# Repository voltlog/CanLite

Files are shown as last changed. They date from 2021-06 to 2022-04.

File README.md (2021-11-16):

# Voltlog CanLite
This repository contains the source files for the CanLite, an ESP32 based CAN development/hacking board which features a built-in automotive grade dc-dc converter as well as an optional two channel high-side automotive grade switch capable of switching up to 1.8A per channel with plenty of protection features.

More info about this project in [Voltlog #370](https://youtu.be/DLKQcw506ck) & [Voltlog #390](https://youtu.be/_m2UW_pron4).
If you would like to order one of these boards ready assembled, check out my [Tindie store](https://voltlog.com/y/canlite).

### Changelog
- revD: Switched to a different inductor, [different high-side switch](https://www.infineon.com/dgdl/Infineon-BTS452T-DS-v01_01-EN.pdf?fileId=5546d4625a888733015aa9afaf0f35d1), optimised layout.
- revC: Switched to a different inductor pn, added some IO access via test points.
- revB: Fixed some bugs from revA.
- revA: Initial release.

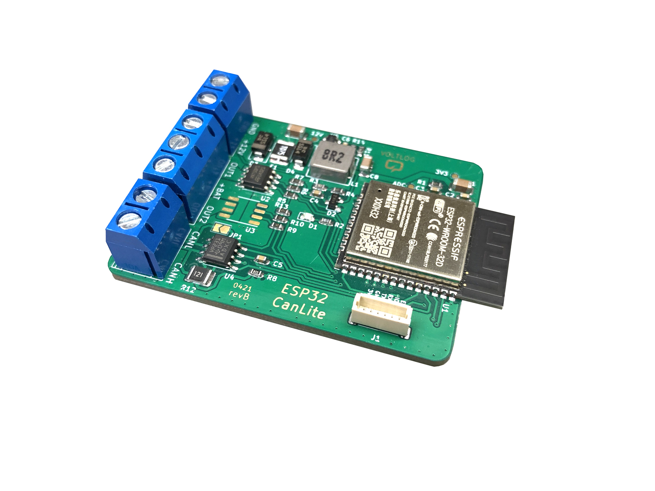
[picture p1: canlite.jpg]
Image of the assembled PCB


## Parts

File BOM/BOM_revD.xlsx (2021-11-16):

Qty | Reference(s) | Value | Footprint | Datasheet | LCSC | PN | Voltage
5 | C1, C4, C6, C7, C8 | 0.1uF | Capacitor_SMD:C_0603_1608Metric | ~
2 | C2, C3 | 10uF | Capacitor_SMD:C_1206_3216Metric | https://datasheet.lcsc.com/szlcsc/1912111437_Murata-Electronics-GRM21BR61E106MA73L_C391262.pdf | C391262 | GRM21BR61E106MA73L | 35V
1 | C5 | 22uF | Capacitor_SMD:C_1206_3216Metric | https://datasheet.lcsc.com/szlcsc/1912111437_Murata-Electronics-GRM31CR70J226KE19L_C408152.pdf | C408152 | GRM31CR70J226KE19L
2 | D1, D2 | SS14 | Diode_SMD:D_SMA | ~
1 | D3 | LED | LED_SMD:LED_0603_1608Metric | ~
1 | D4 | BAS40-04 | Package_TO_SOT_SMD:SOT-23 | http://www.vishay.com/docs/85701/bas40v.pdf
1 | F1 | 0.5A | Fuse:Fuse_1812_4532Metric | https://datasheet.lcsc.com/szlcsc/1809292114_TLC-Electronic-TLC-MSMD075_C262024.pdf | C262024 | TLC-MSMD075
1 | J1 | 12V | TerminalBlock_RND:TerminalBlock_RND_205-00232_1x02_P5.08mm_Horizontal | ~
1 | J2 | CAN | TerminalBlock_RND:TerminalBlock_RND_205-00232_1x02_P5.08mm_Horizontal | ~
1 | J3 | VOLTLINK | Connector_JST:JST_SH_BM06B-SRSS-TB_1x06-1MP_P1.00mm_Vertical | ~
1 | J4 | Conn_01x03 | TerminalBlock_RND:TerminalBlock_RND_205-00233_1x03_P5.08mm_Horizontal | ~
1 | JP1 | NO | Jumper:SolderJumper-2_P1.3mm_Open_TrianglePad1.0x1.5mm | ~
1 | L1 | 8.2uH | voltlog:Inductor_7.5x6.6 |  | C436550 | PSPMAA0603-8R2M-ANF
4 | R1, R7, R8, R10 | 10K | Resistor_SMD:R_0603_1608Metric | ~
1 | R2 | 28K | Resistor_SMD:R_0603_1608Metric | ~
1 | R3 | 8.45K | Resistor_SMD:R_0603_1608Metric | ~
1 | R4 | 1K | Resistor_SMD:R_0603_1608Metric | ~
1 | R5 | 120 | Resistor_SMD:R_1210_3225Metric | ~
1 | R6 | 100K | Resistor_SMD:R_0603_1608Metric | ~
1 | R9 | 36K | Resistor_SMD:R_0603_1608Metric | ~
1 | U1 | LMR14006 | Package_TO_SOT_SMD:SOT-23-6 | https://www.ti.com/lit/ds/symlink/lmr14006.pdf?ts=1611109108480
1 | U2 | ESP32-WROOM-32 | RF_Module:ESP32-WROOM-32 | https://www.espressif.com/sites/default/files/documentation/esp32-wroom-32d_esp32-wroom-32u_datasheet_en.pdf
1 | U3 | SN65HVD231 | Package_SO:SOIC-8_3.9x4.9mm_P1.27mm | http://www.ti.com/lit/ds/symlink/sn65hvd230.pdf
2 | U4, U5 | BTS452T | Package_TO_SOT_SMD:TO-252-4 | https://www.infineon.com/dgdl/Infineon-BTS452T-DS-v01_01-EN.pdf?fileId=5546d4625a888733015aa9afaf0f35d1

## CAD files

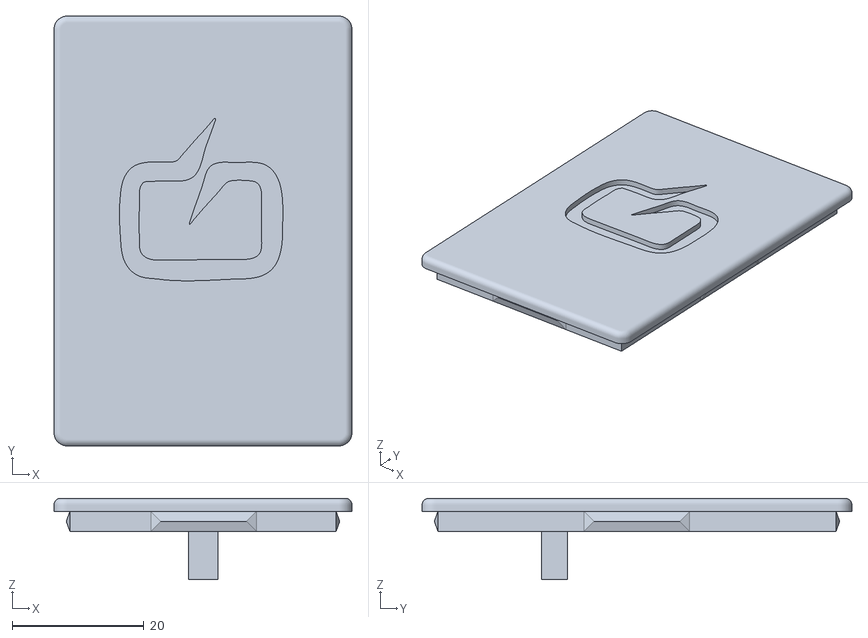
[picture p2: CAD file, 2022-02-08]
3D print enclosure/CANLite_Case/CANLite_Cover_with_Logo.stl
45.2 x 65.2 x 12.4

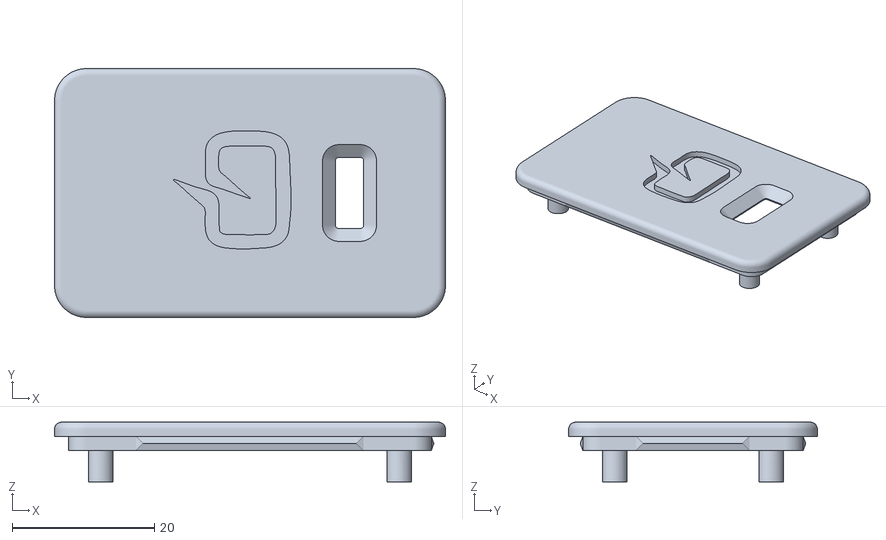
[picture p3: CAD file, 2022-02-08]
3D print enclosure/VoltLink_Case/Cover_with_Logo.stl
55.0 x 35.0 x 8.40

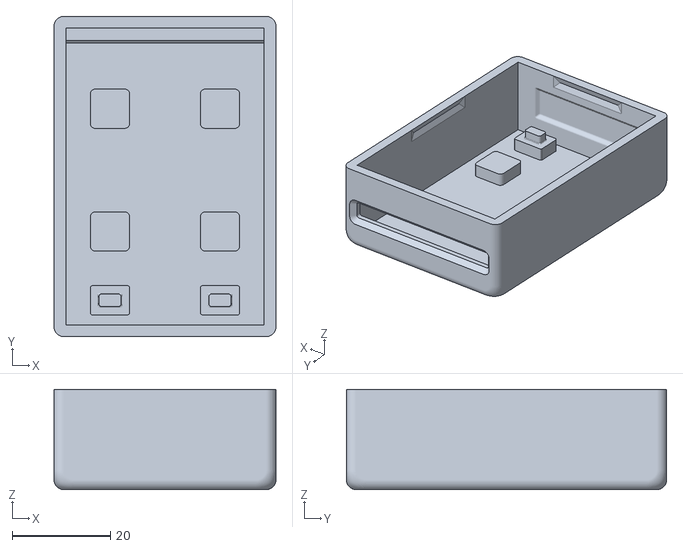
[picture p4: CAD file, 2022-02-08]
3D print enclosure/CANLite_Case/CANLite_Case.stl
45.2 x 65.2 x 20.4

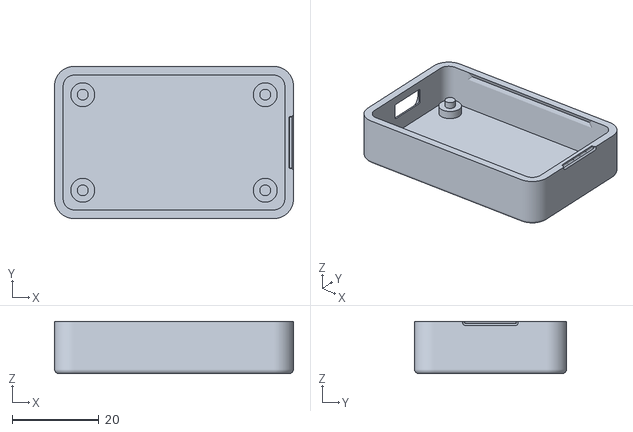
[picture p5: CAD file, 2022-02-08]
3D print enclosure/VoltLink_Case/Case.stl
55.0 x 35.0 x 12.0

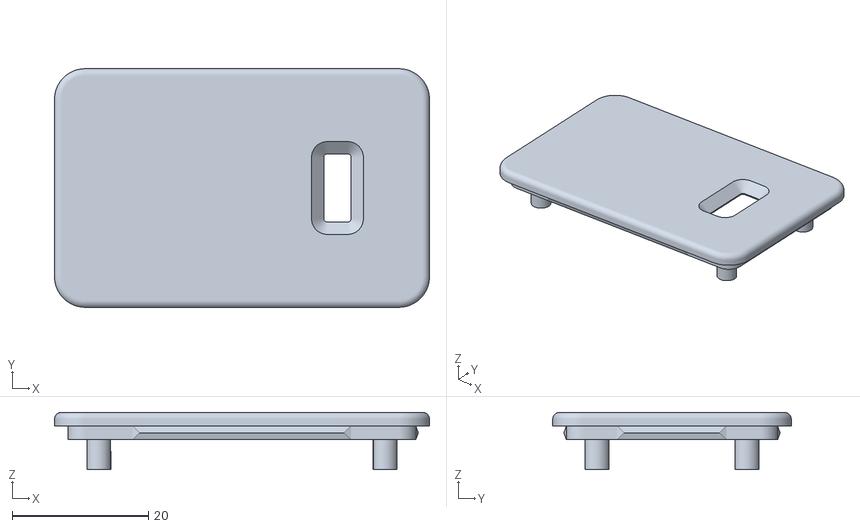
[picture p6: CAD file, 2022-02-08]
3D print enclosure/VoltLink_Case/Cover_without_Logo.stl
55.0 x 35.0 x 8.40

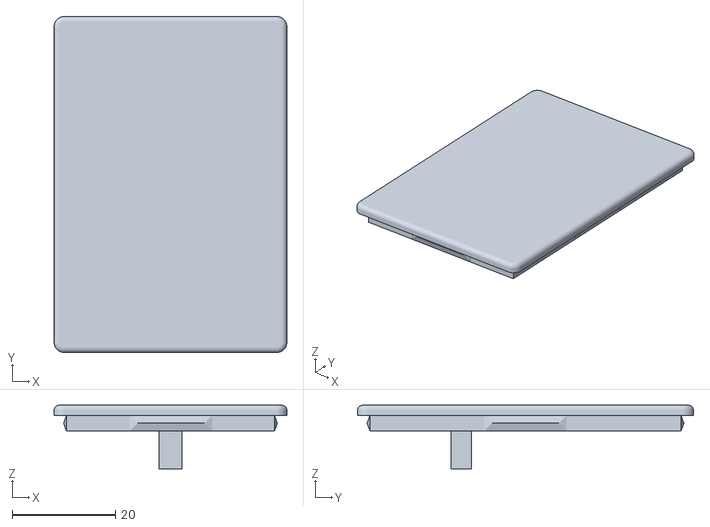
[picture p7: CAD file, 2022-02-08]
3D print enclosure/CANLite_Case/CANLite_Cover_without_Logo.stl
45.2 x 65.2 x 12.4

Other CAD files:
3D print enclosure/CANLite_Case/CANLite_Cover_without_Logo_Sharp.stl

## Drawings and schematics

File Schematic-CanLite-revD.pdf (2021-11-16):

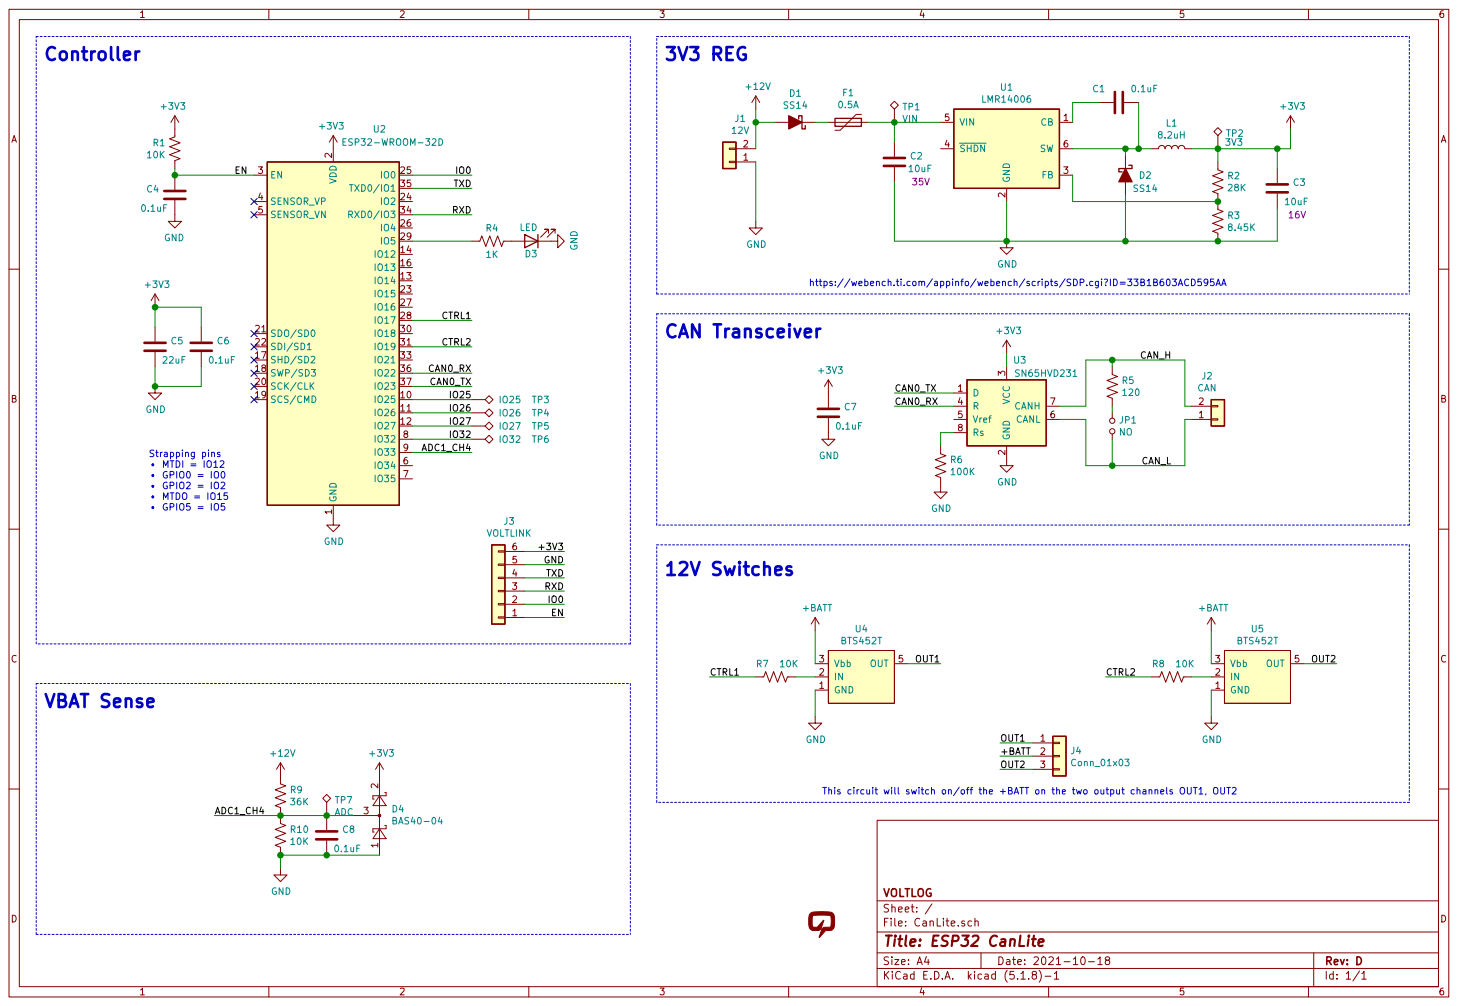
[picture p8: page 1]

2 FB 3 SHDN 4 VIN 5 SW 6 U1

2 SCK/CLK 20 SDO/SD0 21 SDI/SD1 22

https://webench.ti.com/appinfo/webench/scripts/SDP.cgi?ID=33B1B603ACD595AA

File: CanLite.sch Sheet: / VOLTLOG

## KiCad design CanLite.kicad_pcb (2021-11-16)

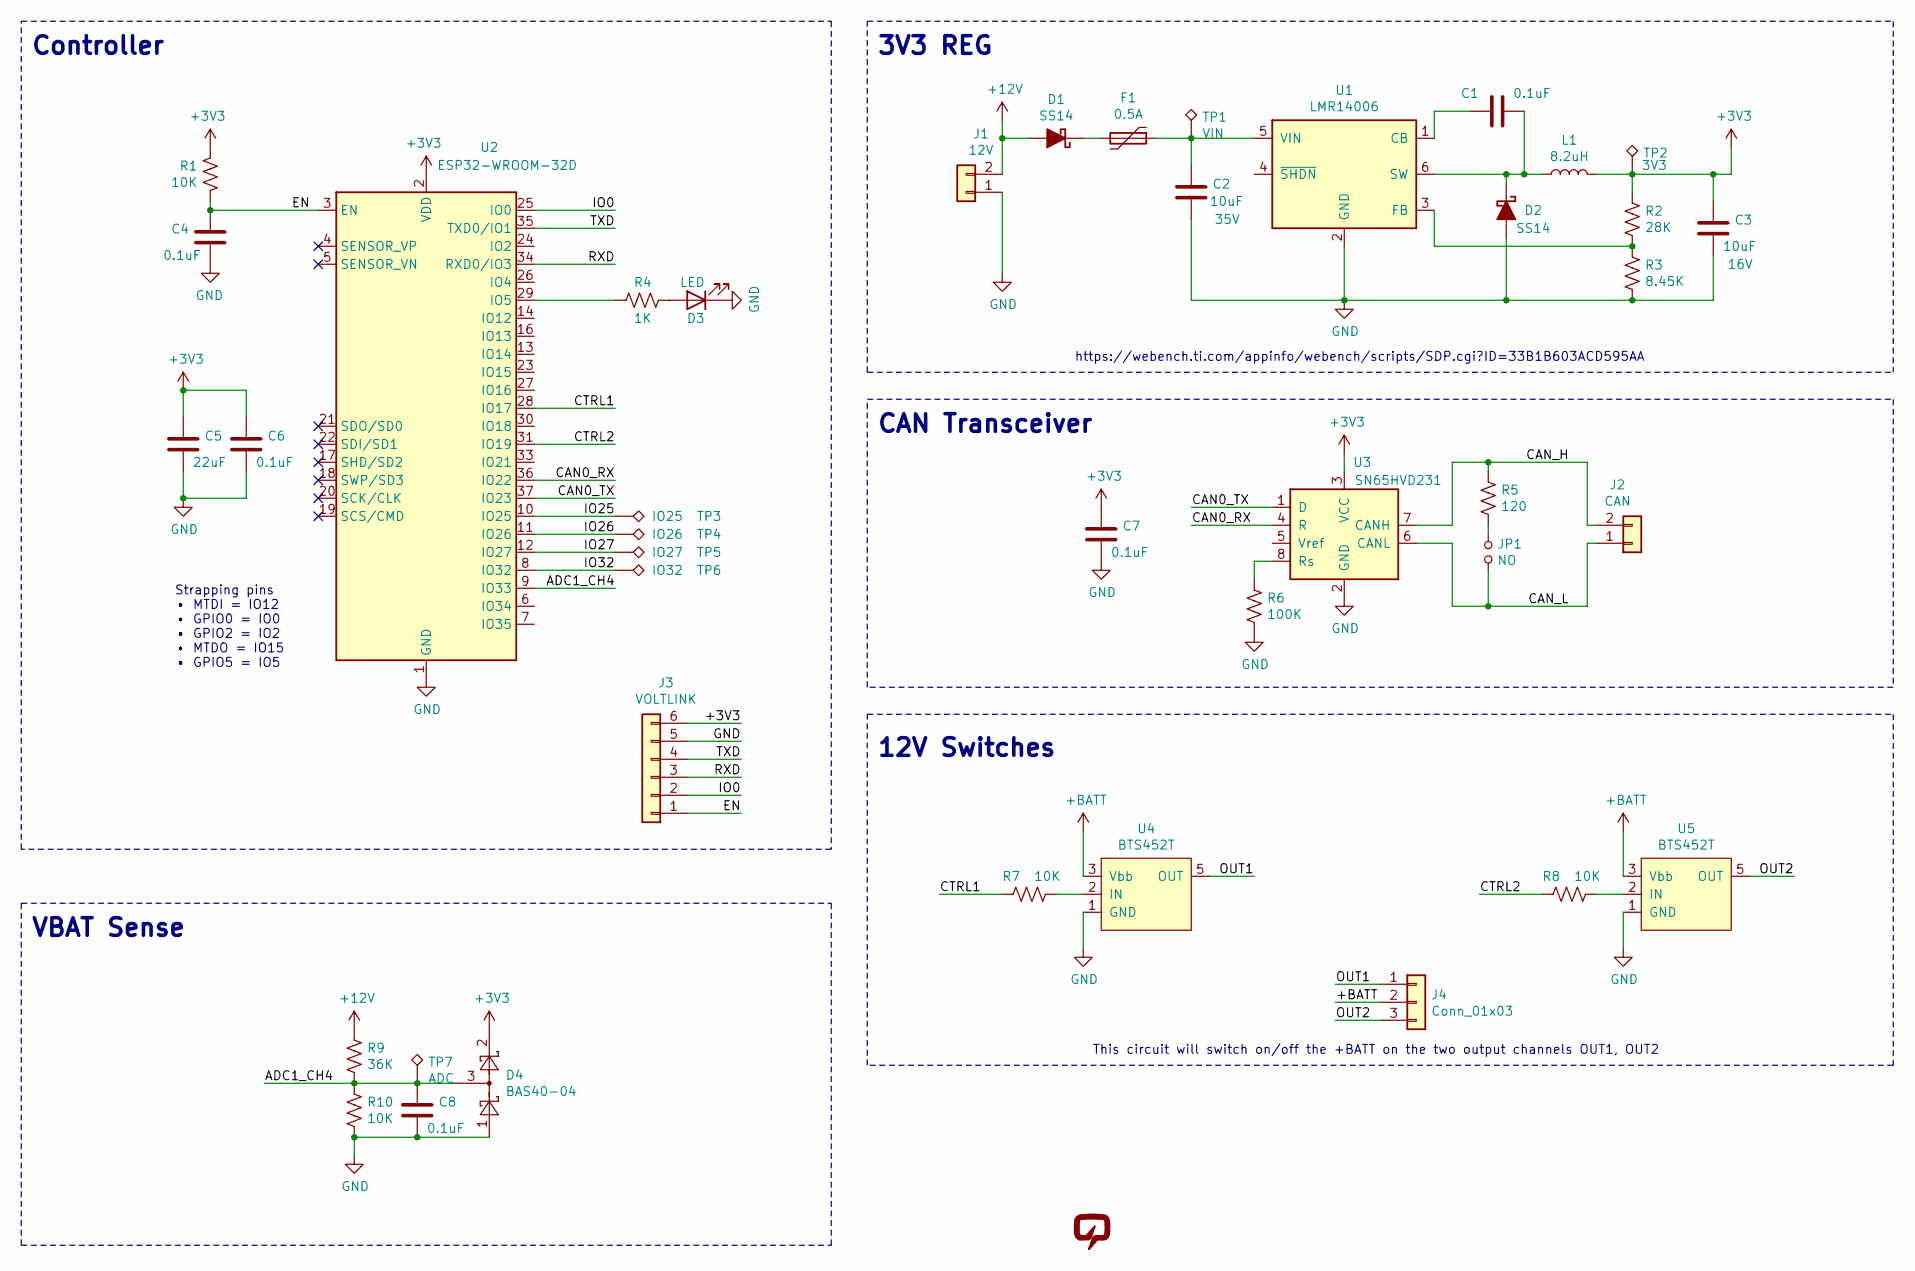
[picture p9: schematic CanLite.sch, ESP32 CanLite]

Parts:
C1, C4, C6, C7, C8: 0.1uF; C_0603_1608Metric
C2: 10uF; C_1206_3216Metric; Voltage 35V; LCSC C391262
C3: 10uF; C_1206_3216Metric; Voltage 16V; LCSC C408152
C5: 22uF; C_1206_3216Metric; LCSC C408152
D1, D2: SS14; D_SMA
D3: LED; LED_0603_1608Metric
D4: BAS40-04; SOT-23
F1: 0.5A; Fuse_1812_4532Metric; LCSC C262024
J1: 12V; TerminalBlock_RND_205-00232_1x02_P5.08mm_Horizontal
J2: CAN; TerminalBlock_RND_205-00232_1x02_P5.08mm_Horizontal
J3: VOLTLINK; JST_SH_BM06B-SRSS-TB_1x06-1MP_P1.00mm_Vertical
J4: Conn_01x03; TerminalBlock_RND_205-00233_1x03_P5.08mm_Horizontal
JP1: NO; SolderJumper-2_P1.3mm_Open_TrianglePad1.0x1.5mm
L1: 8.2uH; Inductor_7.5x6.6; LCSC C436550
R1, R7, R8, R10: 10K; R_0603_1608Metric
R2: 28K; R_0603_1608Metric
R3: 8.45K; R_0603_1608Metric
R4: 1K; R_0603_1608Metric
R5: 120; R_1210_3225Metric
R6: 100K; R_0603_1608Metric
R9: 36K; R_0603_1608Metric
TP1: VIN; TestPoint_Pad_D1.0mm
TP2: 3V3; TestPoint_Pad_D1.0mm
TP3: IO25; TestPoint_Pad_D1.0mm
TP4: IO26; TestPoint_Pad_D1.0mm
TP5: IO27; TestPoint_Pad_D1.0mm
TP6: IO32; TestPoint_Pad_D1.0mm
TP7: ADC; TestPoint_Pad_D1.0mm
U1: LMR14006; SOT-23-6
U2: ESP32-WROOM-32D; ESP32-WROOM-32
U3: SN65HVD231; SOIC-8_3.9x4.9mm_P1.27mm
U4, U5: BTS452T; TO-252-4
V1: VOLTLOG_LOGO; voltlog_mask_3mm

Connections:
+3V3: C3.1, C5.1, C6.1, C7.1, D4.2, J3.6, L1.2, R1.1, R2.1, TP2.1, U2.2 (VDD), U3.3 (VCC)
+12V: D1.2 (A), J1.2, R9.1
+BATT: J4.2, U4.3 (Vbb), U5.3 (Vbb)
/ADC1_CH4: C8.1, D4.3, R9.2, R10.1, TP7.1, U2.9 (IO33)
/CAN0_RX: U2.36 (IO22), U3.4 (R)
/CAN0_TX: U2.37 (IO23), U3.1 (D)
/CAN_H: J2.2, R5.1, U3.7 (CANH)
/CAN_L: J2.1, JP1.2, U3.6 (CANL)
/CTRL1: R7.2, U2.28 (IO17)
/CTRL2: R8.2, U2.31 (IO19)
/EN: C4.1, J3.1, R1.2, U2.3 (EN)
/IO0: J3.2, U2.25 (IO0)
/IO25: TP3.1, U2.10 (IO25)
/IO26: TP4.1, U2.11 (IO26)
/IO27: TP5.1, U2.12 (IO27)
/IO32: TP6.1, U2.8 (IO32)
/OUT1: J4.1, U4.5 (OUT)
/OUT2: J4.3, U5.5 (OUT)
/RXD: J3.3, U2.34 (RXD0/IO3)
/TXD: J3.4, U2.35 (TXD0/IO1)
GND: C2.2, C3.2, C4.2, C5.2, C6.2, C7.2, C8.2, D2.2 (A), D3.1 (K), D4.1, J1.1, J3.5, R3.2, R6.2, R10.2, U1.2 (GND), U2.1 (GND), U2.15 (GND), U2.38 (GND), U2.39 (GND), U3.2 (GND), U4.1 (GND), U5.1 (GND)
unnamed: C1.1, U1.1 (CB)
unnamed: C1.2, D2.1 (K), L1.1, U1.6 (SW)
unnamed: C2.1, F1.1, TP1.1, U1.5 (VIN)
unnamed: D1.1 (K), F1.2
unnamed: D3.2 (A), R4.1
unnamed: JP1.1, R5.2
unnamed: R2.2, R3.1, U1.3 (FB)
unnamed: R4.2, U2.29 (IO5)
unnamed: R6.1, U3.8 (Rs)
unnamed: R7.1, U4.2 (IN)
unnamed: R8.1, U5.2 (IN)

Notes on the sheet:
Strapping pins • MTDI = IO12 • GPIO0 = IO0 • GPIO2 = IO2 • MTDO = IO15 • GPIO5 = IO5
This circuit will switch on/off the +BATT on the two output channels OUT1, OUT2
https://webench.ti.com/appinfo/webench/scripts/SDP.cgi?ID=33B1B603ACD595AA
Controller
VBAT Sense
3V3 REG
CAN Transceiver
12V Switches

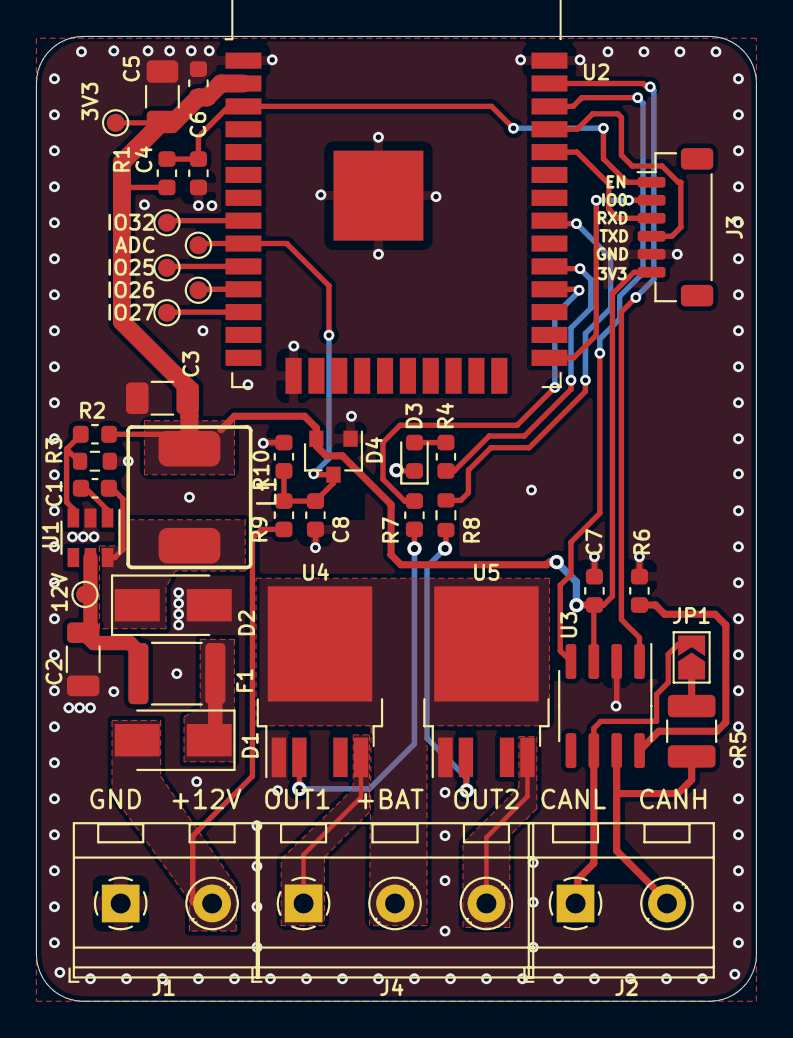
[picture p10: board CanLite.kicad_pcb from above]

Board: 2 copper layers, 40.0 x 53.6 mm, 42 parts (0 on the bottom side), 32 nets.

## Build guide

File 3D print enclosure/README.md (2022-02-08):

Ammar, a CANLite user contributed this CANLite and VoltLink 3D-printable case design.

The CANLite case wall that is facing the ESP32 antenna is thinner for better WiFi signal penetration - or so I hope.
The opening for the wires is about 2mm wider to allow for the VoltLink 6-wires cable to pass through. This way I can easily reprogram the CANLite without having to open its case. 

------------------
 3D Printing Tips
------------------
Best printed with PETG or ABS plastics. I had better results with Prusa PETG.

ABS Settings: 
Bed temp for first layer: 100
Bed temp for the rest: 110
Nozzle temp for first layer: 255
Nozzle temp for the rest: 258
Fan Speed: Min 25% - Max 25%

--------------------------------

PETG Settings:
Bed temp for first layer: 90
Bed temp for the rest: 92
Nozzle temp for first layer: 238
Nozzle temp for the rest: 242
Fan Speed: Min 30% - Max 50%

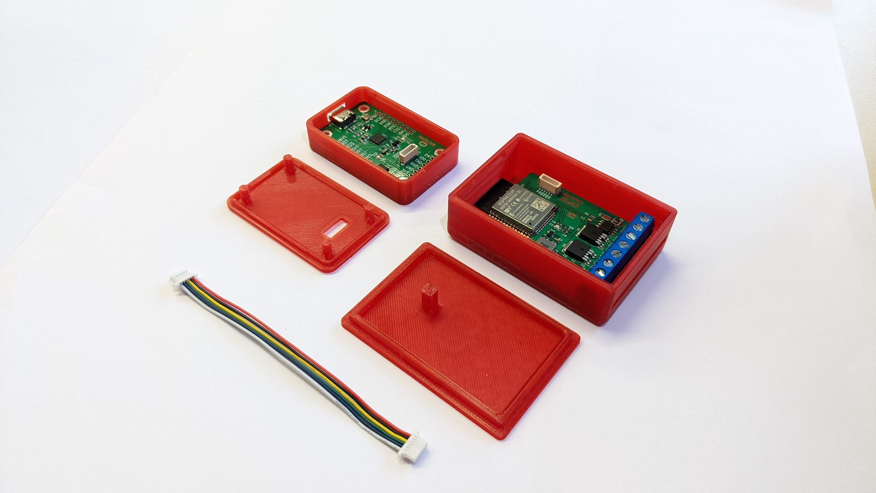
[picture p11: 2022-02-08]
3D print enclosure/Pictures/3d printed 1.jpg

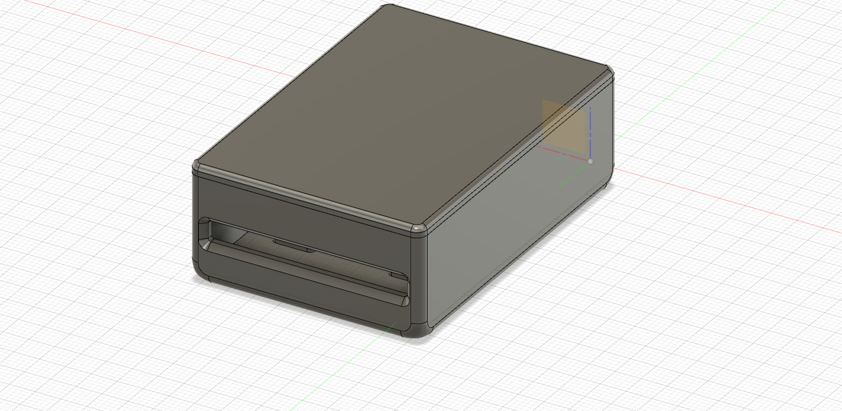
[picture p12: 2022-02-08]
3D print enclosure/Pictures/CANLite_Case.png

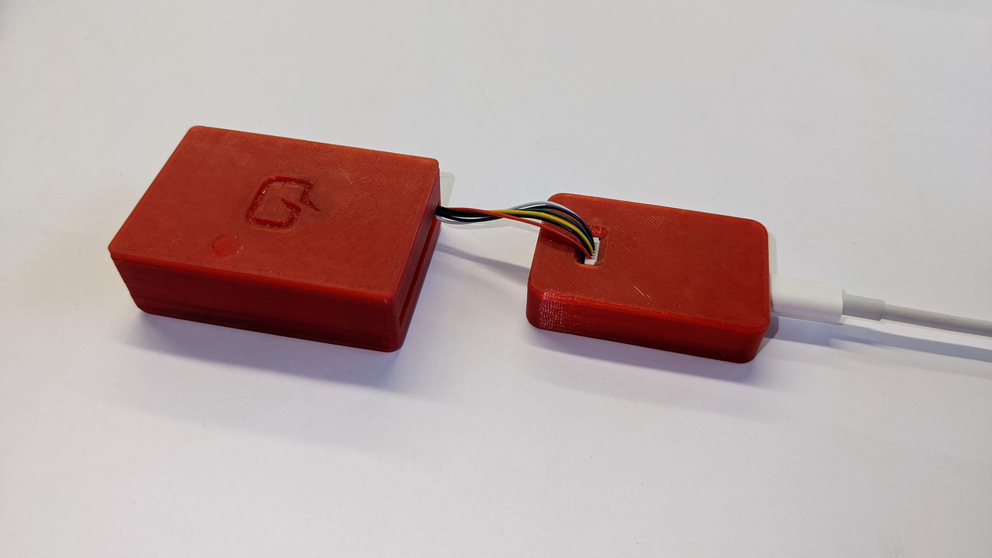
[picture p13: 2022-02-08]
3D print enclosure/Pictures/3d printed 2.jpg

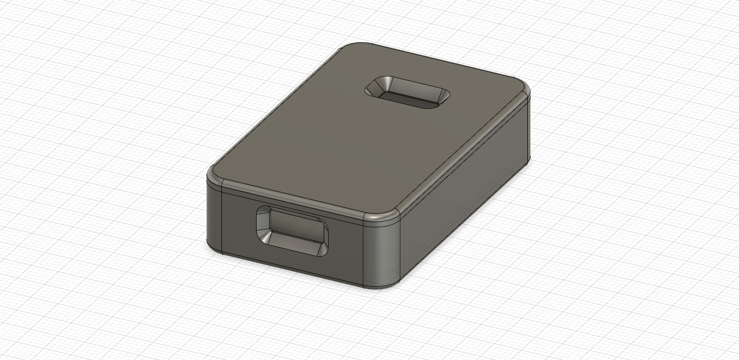
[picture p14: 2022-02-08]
3D print enclosure/Pictures/VoltLink_Case.png

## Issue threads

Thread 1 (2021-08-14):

Code for the CanLite

lukilukeskywalker, 2021-08-14:
Hi!!!

Is there any code for the CanLite? I am mostly interested in the part of the CAN bus

Thanks

voltlog, 2021-08-15:
Hi,
Currently there is no example code for the CanLite. I am working on that, but due to a busy schedule it will take a while until I can get that task done. In the meantime you can use any generic ESP32 CAN interface example code. There are numerous projects on the web on the topic, [here is for example a project based on Arduino.](https://github.com/skpang/esp32can_demo)

Closed 2021-08-15.

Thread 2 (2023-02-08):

The footprint for voltlog:Inductor_7.5x6.6 is missing.

michaelhay, 2023-02-08:

voltlog, 2023-02-09:
What you are reporting is not possible, because of this (extracted from kicad User Manual)
"KiCad schematic and board files contain all the schematic symbols and footprints used in the design, so you
can back up or send these files by themselves with no issue"
Link: https://docs.kicad.org/6.0/en/kicad/kicad.pdf

Closed 2023-02-09.

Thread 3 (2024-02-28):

esp32 CANlite

nielser1, 2024-02-28:
Hello voltog,
Ik have a little question for the esp32 CANlite, is it possible to feed this board with a 5 volt?
because i get the power out of a battery with CAN and the output of that is 5V

voltlog, 2024-03-14:
This might be a little bit out of spec but I think it will work with 5V input.

Closed 2024-03-14.

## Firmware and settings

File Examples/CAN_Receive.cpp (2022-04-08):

/* Demo code for the Voltlog CanLite development board 
*  https://voltlog.com/y/canlite
*
*  This code will continously forward packets received on the CAN interface 
*  to the serial port at the configured baud rates.
*
*  Created 8-Apr-2022, based on original example from sandeepmistry Arduino CAN library
*  Uses Arduino CAN library by sandeepmistry https://github.com/sandeepmistry/arduino-CAN
*/
#include <Arduino.h>
#include <CAN.h>

#define LED 5      // On board LED
//#define OUT1 17     // OUT1 via U2
//#define STATUS1 16  // STATUS of U2
//#define OUT2 19     // OUT2 via U3
//#define STATUS2 18  // STATUS of U2
#define CANRX GPIO_NUM_22 // Define CAN RX pin
#define CANTX GPIO_NUM_23 // Define CAN TX pin
#define CANSPEED 500E3  //define can speed

void setup() {
  Serial.begin(115200);
  while (!Serial);

  Serial.println("Voltlog CanLite CAN Receiver Demo");
  Serial.print("Setting up CAN interface for ");
  Serial.print((int)CANSPEED);
  Serial.print(" baud rate \r\n");

  CAN.setPins(CANRX, CANTX);

  // start the CAN bus at 500 kbps
  if (!CAN.begin(CANSPEED)) {
    Serial.println("Starting CAN failed!");
    while (1);
  }
}

void loop() {
  // try to parse packet
  int packetSize = CAN.parsePacket();

  if (packetSize) {
    // received a packet
    Serial.print("Received ");

    if (CAN.packetExtended()) {
      Serial.print("extended ");
    }

    if (CAN.packetRtr()) {
      // Remote transmission request, packet contains no data
      Serial.print("RTR ");
    }

    Serial.print("packet with id 0x");
    Serial.print(CAN.packetId(), HEX);

    if (CAN.packetRtr()) {
      Serial.print(" and requested length ");
      Serial.println(CAN.packetDlc());
    } else {
      Serial.print(" and length ");
      Serial.print(packetSize);
      Serial.print(" [");

      // only print packet data for non-RTR packets
      while (CAN.available()) {
        Serial.print((char)CAN.read(), HEX);
      }
      Serial.print("] \r\n");
    }

    Serial.println();
  }
}

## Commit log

2021-11-16 Released rev.D
    [BOM_revB.xlsx, BOM_revD.xlsx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]
2022-02-08 Migrated project to Kicad V6
2022-02-08 Added user contributed 3d printed case design
    [CANLite_Case.stl, CANLite_Cover_with_Logo.stl, CANLite_Cover_without_Logo.stl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]
